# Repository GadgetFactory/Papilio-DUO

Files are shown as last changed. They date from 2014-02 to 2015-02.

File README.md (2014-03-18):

Papilio-DUO
==============
This is the next generation Papilio FPGA board with a Spartan6 Powered Papilio FPGA on the top and an atmega32u4 Arduino derived design on the bottom.

Features
--------
* Arduino Mega Footprint
* Spartan 6 FPGA
* SRAM 512K-2MB
* FT2232H USB
* atmega32u4 AVR

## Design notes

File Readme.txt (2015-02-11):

BPC3012 Papilio DUO Manufacturing Package - Current Version 1.7

Special assembly instructions:
	-Use RED for the PCB color and white for the silkscreen color.

Test Plan Home Page:
	- http://www.gadgetfactory.net/opmanuals/index.php?n=Main.PapilioDUO

CHANGELOG
2/11/2015 V1.7
	-Added a 2MB and 512KB marking to the top silkscreen.

1/7/2015 V1.6
	-Made the through holes for mounting on the micro-usb via's instead of holes so they can be soldered.
	-Removed Kickstarter edition
	-Fixed angles on some of the traces
	-PCB color is RED now.

9/30/2014 V1.5 - Kickstarter Edition
	-Added TQFP footprint for the ATmega32U4
	-Changed values for LED resistors so they won't be so bright. R7, R29, R30
	-Changed size of the EEPROM used by the FT2232H chip from 1K to 2K. This allows us to look like official Xilinx Cable. U3
	-Fixed up some silkscreen markings to make it more obvious how to place the parts.
	-Added the Kickstarter Special Edition Marking
	-Changed PCB color to Black

7/30/2014 V1.4
	-Added getting started URL
	-Fixed full silkscreen	

6/4/2014 V1.4
	-Fixed the mounting holes
	-Removed original Arduino mounting holes

4/16/2014 V1.3
	-VBUS connected
	-RX/TX LED's changed to port B
	-Silkscreen changes
	-HDMI removed

3/5/2014 V1.2
	-Shrunk the board to 100cm in order to better fit Chinese standards and save money in manufacturing.

3/5/2014 V1.1
	-Fixed problems for manufacturability (thanks to Mitch at Hackvana)
		-Fixed clearance problem on FPGA pins 144 and 36
		-Moved trace between FT2232H pins 10 and 11 to inside of part so it does not look like a solder bridge up on inspection.
		-Fixed Silkscreen size for the 22-53 numbering
		-Updated the CC-BY-SA text to indicate license number CC-BY-SA 4.0

3/3/2014 V1.0
	Initial Release

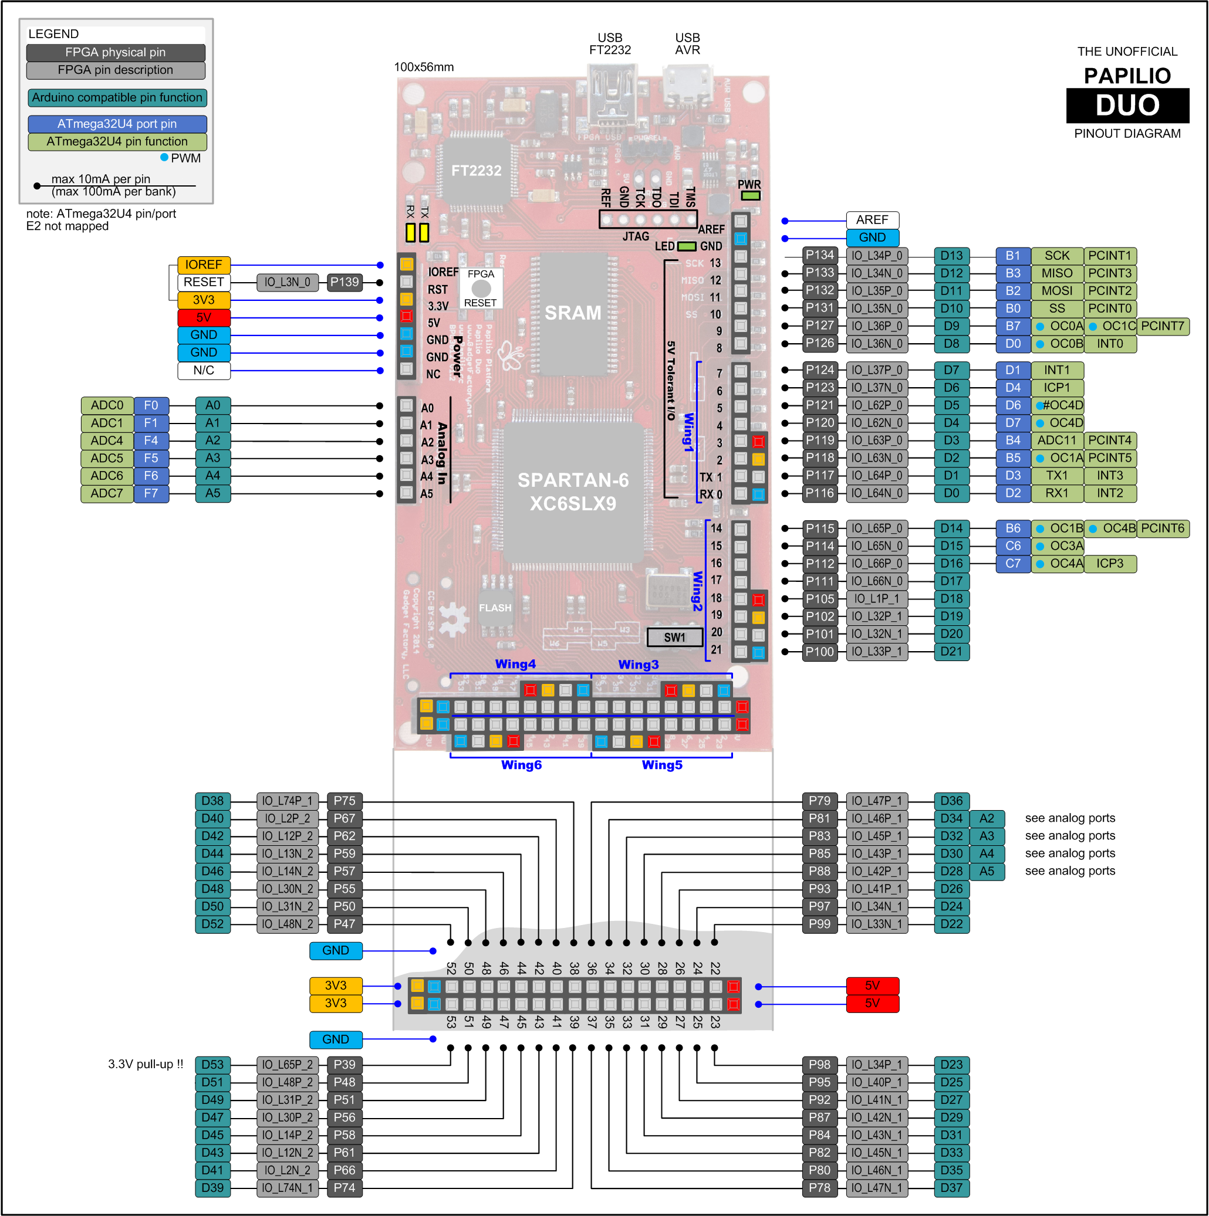
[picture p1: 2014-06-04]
Papilio DUO pinout.png

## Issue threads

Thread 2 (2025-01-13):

Papilio-One ?

nsauzede, 2025-01-13:
Hello!
I still have a working Papilio One 500k board, that I managed to undust and program fine,
but can't seem to find the corresponding schematics and design files, like found for the Duo in this repo.
Some pages of the original Gadgetfactory website (including Papilio One hardware doc etc..) seem to be unaccessible nowadays..
Would it be possible to upload a Papilio One github repo her, just like for the Duo and/or fix the Papilio One Gadgetfactory hardware doc webpages ?
Thanks by advance!

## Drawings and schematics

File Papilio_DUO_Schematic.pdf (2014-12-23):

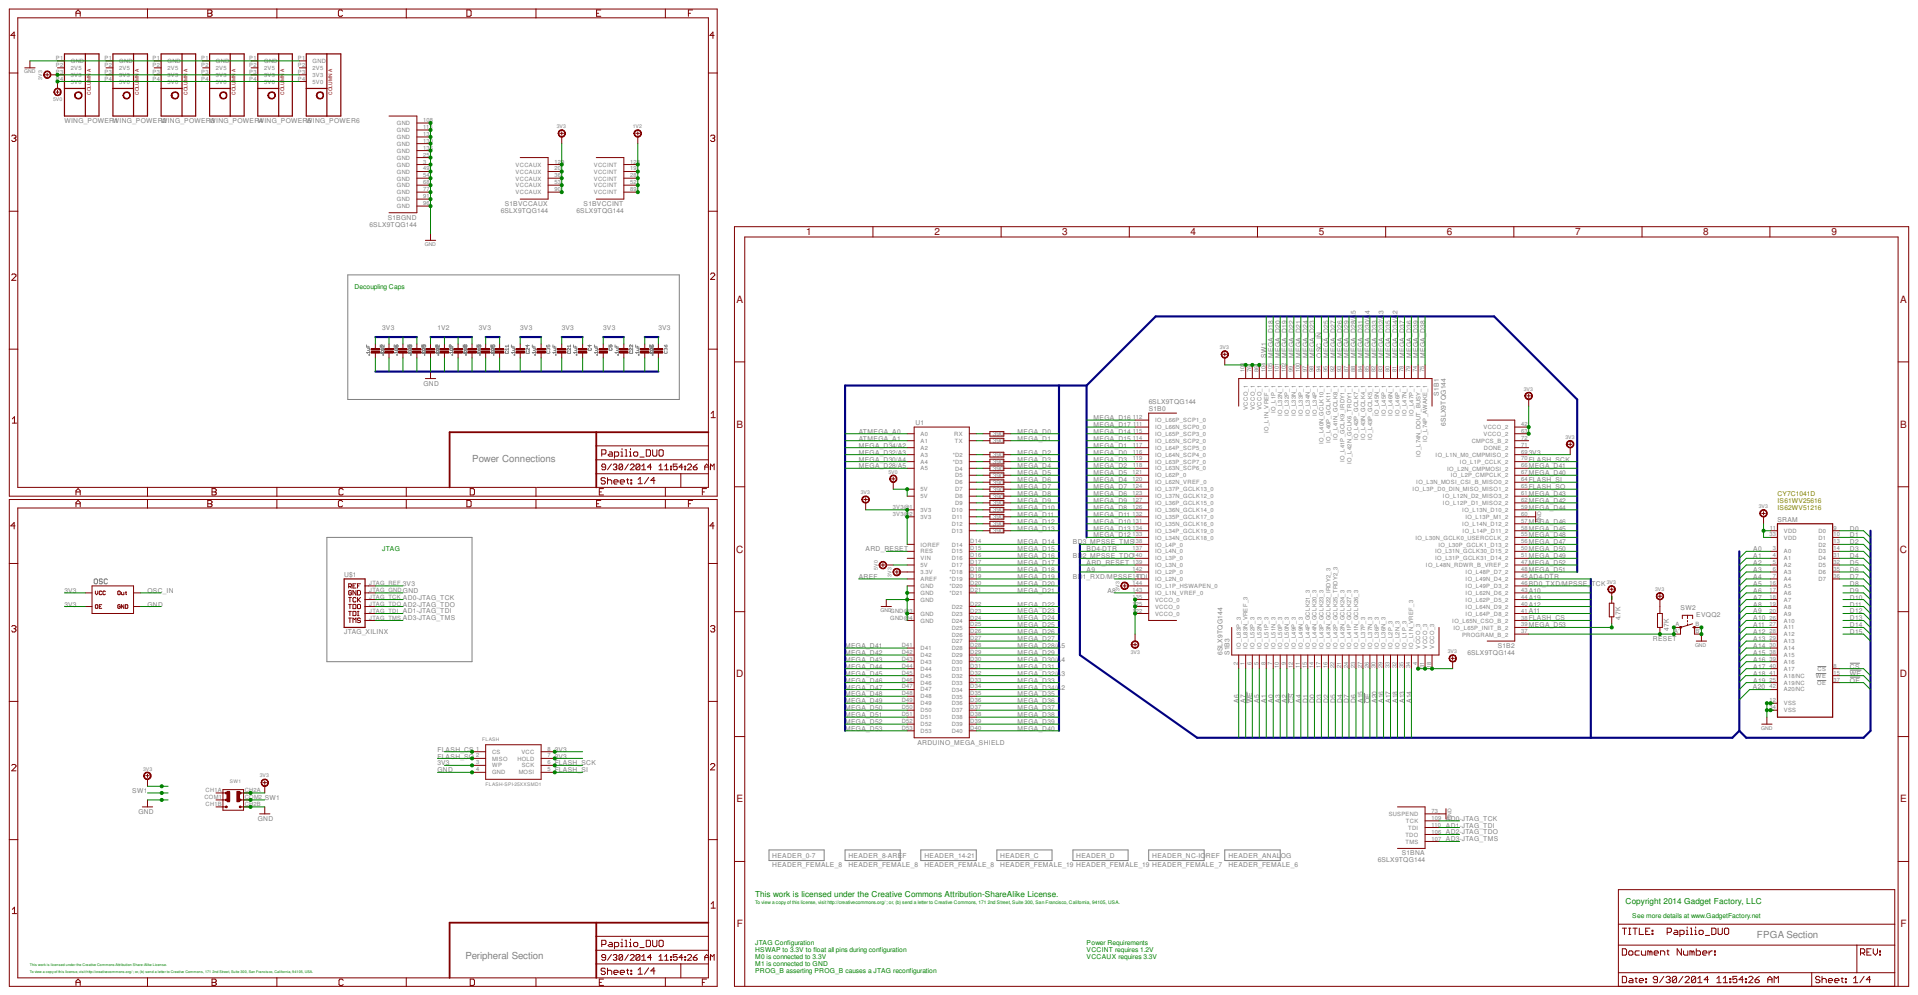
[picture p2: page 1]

MEGA_D53 | MEGA_D40

This work is licensed under the Creative Commons Attribution-ShareAlike License.
To view a copy of this license, visit http://creativecommons.org/ ; or, (b) send a letter to Creative Commons, 171 2nd Street, Suite 300, San Francisco, California, 94105, USA.

Copyright 2014 Gadget Factory, LLC

See more details at www.GadgetFactory.net

JTAG Configuration
HSWAP to 3.3V to float all pins during configuration
M0 is connected to 3.3V
M1 is connected to GND
PROG_B asserting PROG_B causes a JTAG reconfiguration

This work is licensed under the Creative Commons Attribution Share-Alike License.

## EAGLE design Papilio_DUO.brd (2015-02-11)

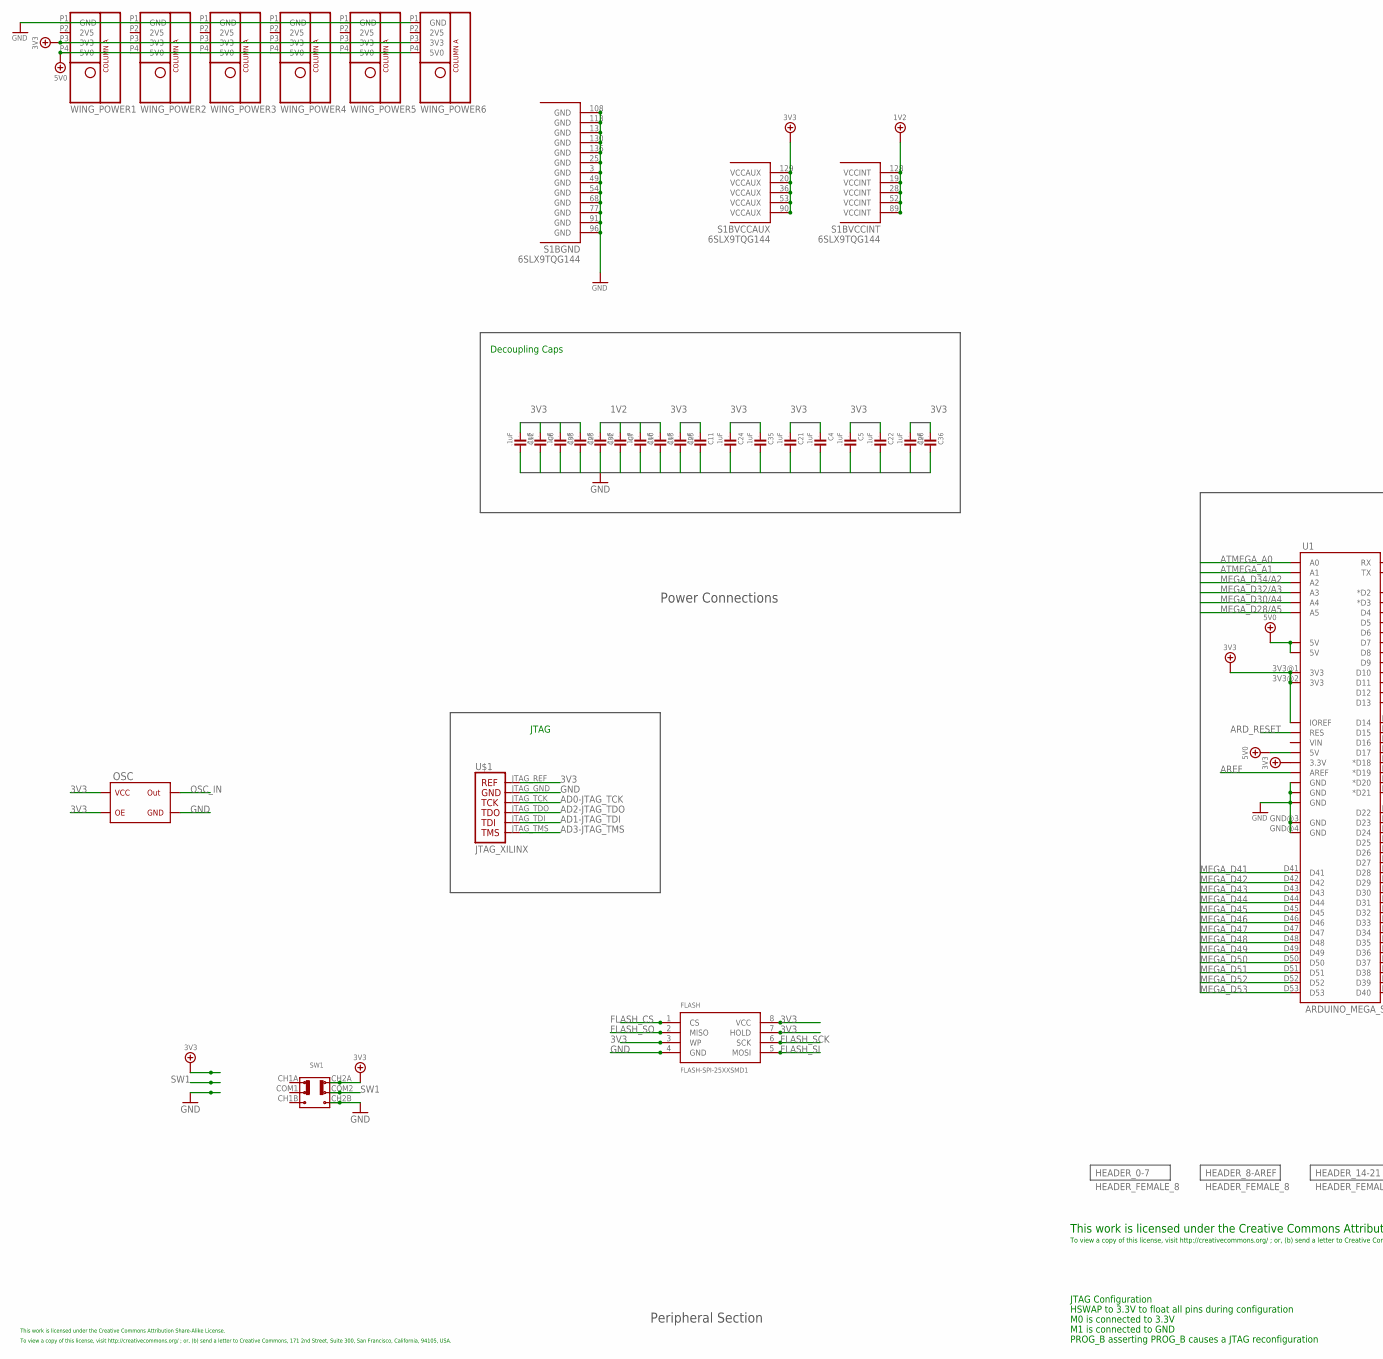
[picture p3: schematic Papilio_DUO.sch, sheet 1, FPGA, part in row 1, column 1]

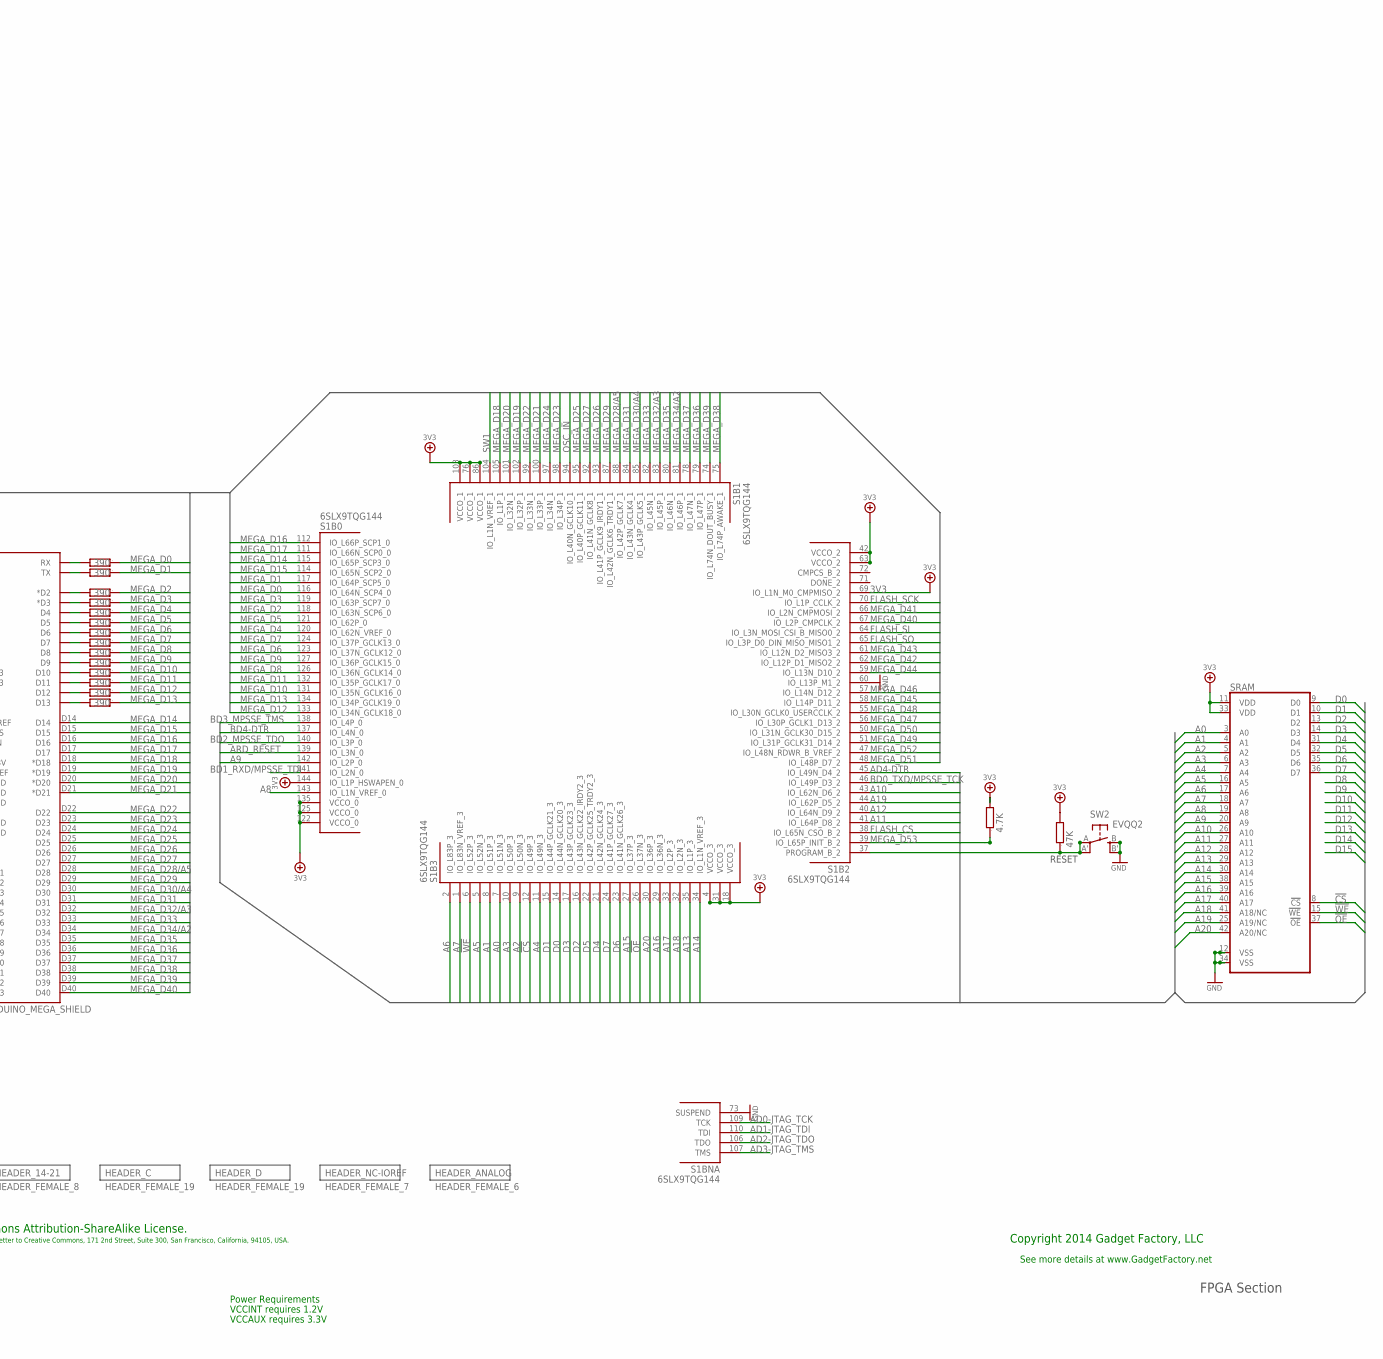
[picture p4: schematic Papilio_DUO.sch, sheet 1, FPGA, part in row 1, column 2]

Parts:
C4, C5, C6, C7, C10, C11, C12, C13, C21, C22, C23, C24, C25, C26, C32, C33, C35, C36: .1uF; 0603; PARTNO GRM188F51E104ZA01D
FLASH: FLASH-SPI-25XXSMD1; SO08-EIAJ; PARTNO MX25L6445EM2I-10G
OSC: OSC1; PARTNO ASV-32.000MHZ-E-T
R8, R9, R10, R11, R12, R13, R14, R15, R16, R17, R18, R19, R20, R21: 390; 0603; PARTNO RMCF0603JT390R
R31: 47K; 0805; PARTNO RMCF0805JT47K0
R32: 4.7K; 0603; PARTNO RMCF0603JT4K70
S1: 6SLX9TQG144; TQ144; PARTNO XC6SLX9-2TQG144C
SRAM: ISSI_SRAM_8BIT; TSOP44-II; PARTNO IS61WV20488BLL-10TLI
SW1: SWITCH-2CH-6P-3010010P1; 6P-2CH-2.54-9.1X3.5X3.2+2H; PARTNO EG1271
SW2: EVQQ2; EVQ-Q2; PARTNO PTS525SM10SMTR LFS
U1: ARDUINO_MEGA_SHIELD
U$1: JTAG_XILINX; JTAG
WING_POWER1, WING_POWER2, WING_POWER3, WING_POWER4, WING_POWER5, WING_POWER6: HEADER_FEMALE_4; POWER_NO_TEXT; PARTNO PPTC041LFBN-RC

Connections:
1V2: C7.1, C10.1, C13.1, C32.1, S1.19 (VCCINT), S1.28 (VCCINT), S1.52 (VCCINT), S1.89 (VCCINT), S1.128 (VCCINT); also elsewhere on the board
3V3: C4.1, C5.1, C6.1, C11.1, C12.1, C21.1, C22.1, C23.1, C24.1, C25.1, C26.1, C33.1, C35.1, C36.1, FLASH.3 (WP), FLASH.7 (HOLD), FLASH.8 (VCC), OSC.1@1 (OE), OSC.4@4 (VCC), R31.2, R32.2, S1.4 (VCCO_3), S1.18 (VCCO_3), S1.20 (VCCAUX), S1.31 (VCCO_3), S1.36 (VCCAUX), S1.42 (VCCO_2), S1.53 (VCCAUX), S1.63 (VCCO_2), S1.69 (IO_L1N_M0_CMPMISO_2), S1.76 (VCCO_1), S1.86 (VCCO_1), S1.90 (VCCAUX), S1.103 (VCCO_1), S1.122 (VCCO_0), S1.125 (VCCO_0), S1.129 (VCCAUX), S1.135 (VCCO_0), S1.144 (IO_L1P_HSWAPEN_0), SRAM.11 (VDD), SRAM.33 (VDD), SW1.CH2A, U1.3.3V, U1.3V3@1 (3V3), U1.3V3@2 (3V3), U1.IOREF, U$1.JTAG_REF, WING_POWER1.P3 (3V3), WING_POWER2.P3 (3V3), WING_POWER3.P3 (3V3), WING_POWER4.P3 (3V3), WING_POWER5.P3 (3V3), WING_POWER6.P3 (3V3); also elsewhere on the board
5V0: U1.5V@0 (5V), U1.5V@1 (5V), U1.5V@2 (5V), WING_POWER1.P4 (5V0), WING_POWER2.P4 (5V0), WING_POWER3.P4 (5V0), WING_POWER4.P4 (5V0), WING_POWER5.P4 (5V0), WING_POWER6.P4 (5V0); also elsewhere on the board
!CS: S1.12 (IO_L49P_3), SRAM.8 (!CS)
!OE: S1.26 (IO_L37N_3), SRAM.37 (!OE)
!WE: S1.6 (IO_L52P_3), SRAM.15 (!WE)
A0: S1.7 (IO_L51N_3), SRAM.3 (A0)
A1: S1.8 (IO_L51P_3), SRAM.4 (A1)
A2: S1.9 (IO_L50N_3), SRAM.5 (A2)
A3: S1.10 (IO_L50P_3), SRAM.6 (A3)
A4: S1.11 (IO_L49N_3), SRAM.7 (A4)
A5: S1.5 (IO_L52N_3), SRAM.16 (A5)
A6: S1.2 (IO_L83P_3), SRAM.17 (A6)
A7: S1.1 (IO_L83N_VREF_3), SRAM.18 (A7)
A8: S1.143 (IO_L1N_VREF_0), SRAM.19 (A8)
A9: S1.142 (IO_L2P_0), SRAM.20 (A9)
A10: S1.43 (IO_L62N_D6_2), SRAM.26 (A10)
A11: S1.41 (IO_L64P_D8_2), SRAM.27 (A11)
A12: S1.40 (IO_L64N_D9_2), SRAM.28 (A12)
A13: S1.35 (IO_L1P_3), SRAM.29 (A13)
A14: S1.34 (IO_L1N_VREF_3), SRAM.30 (A14)
A15: S1.27 (IO_L37P_3), SRAM.38 (A15)
A16: S1.29 (IO_L36N_3), SRAM.39 (A16)
A17: S1.33 (IO_L2P_3), SRAM.40 (A17)
A18: S1.32 (IO_L2N_3), SRAM.41 (A18/NC)
A19: S1.44 (IO_L62P_D5_2), SRAM.25 (A19/NC)
A20: S1.30 (IO_L36P_3), SRAM.42 (A20/NC)
AD0-JTAG_TCK: S1.109 (TCK), U$1.JTAG_TCK; also elsewhere on the board
AD1-JTAG_TDI: S1.110 (TDI), U$1.JTAG_TDI; also elsewhere on the board
AD2-JTAG_TDO: S1.106 (TDO), U$1.JTAG_TDO; also elsewhere on the board
AD3-JTAG_TMS: S1.107 (TMS), U$1.JTAG_TMS; also elsewhere on the board
AD4-DTR: S1.45 (IO_L49N_D4_2); also elsewhere on the board
ARD_RESET: S1.139 (IO_L3N_0), U1.RES; also elsewhere on the board
AREF: U1.AREF; also elsewhere on the board
ATMEGA_A0: U1.A0; also elsewhere on the board
ATMEGA_A1: U1.A1; also elsewhere on the board
ATMEGA_D0/RX: R21.2, U1.RX; also elsewhere on the board
ATMEGA_D1/TX: R20.2, U1.TX; also elsewhere on the board
ATMEGA_D2: R19.2, U1.D2 (*D2); also elsewhere on the board
ATMEGA_D3: R18.2, U1.D3 (*D3); also elsewhere on the board
ATMEGA_D4: R17.2, U1.D4; also elsewhere on the board
ATMEGA_D5*: R16.2, U1.D5; also elsewhere on the board
ATMEGA_D6*: R15.2, U1.D6; also elsewhere on the board
ATMEGA_D7: R14.2, U1.D7; also elsewhere on the board
ATMEGA_IO8: R13.2, U1.D8; also elsewhere on the board
ATMEGA_IO9*: R12.2, U1.D9; also elsewhere on the board
ATMEGA_IO10*: R11.2, U1.D10; also elsewhere on the board
ATMEGA_IO11*: R10.2, U1.D11; also elsewhere on the board
ATMEGA_IO12: R9.2, U1.D12; also elsewhere on the board
ATMEGA_IO13*: R8.2, U1.D13; also elsewhere on the board
BD0_TXD/MPSSE_TCK: S1.46 (IO_L49P_D3_2); also elsewhere on the board
BD1_RXD/MPSSE_TDI: S1.141 (IO_L2N_0); also elsewhere on the board
BD2_MPSSE_TDO: S1.140 (IO_L3P_0); also elsewhere on the board
BD3_MPSSE_TMS: S1.138 (IO_L4P_0); also elsewhere on the board
BD4-DTR: S1.137 (IO_L4N_0); also elsewhere on the board
D0: S1.14 (IO_L44N_GCLK20_3), SRAM.9 (D0)
D1: S1.15 (IO_L44P_GCLK21_3), SRAM.10 (D1)
D2: S1.16 (IO_L43N_GCLK22_IRDY2_3), SRAM.13 (D2)
D3: S1.17 (IO_L43P_GCLK23_3), SRAM.14 (D3)
D4: S1.21 (IO_L42N_GCLK24_3), SRAM.31 (D4)
D5: S1.22 (IO_L42P_GCLK25_TRDY2_3), SRAM.32 (D5)
D6: S1.23 (IO_L41N_GCLK26_3), SRAM.35 (D6)
D7: S1.24 (IO_L41P_GCLK27_3), SRAM.36 (D7)
FLASH_CS: FLASH.1 (CS), S1.38 (IO_L65N_CSO_B_2)
FLASH_SCK: FLASH.6 (SCK), S1.70 (IO_L1P_CCLK_2)
FLASH_SI: FLASH.5 (MOSI), S1.64 (IO_L3N_MOSI_CSI_B_MISO0_2)
FLASH_SO: FLASH.2 (MISO), S1.65 (IO_L3P_D0_DIN_MISO_MISO1_2)
GND: C4.2, C5.2, C6.2, C7.2, C10.2, C11.2, C12.2, C13.2, C21.2, C22.2, C23.2, C24.2, C25.2, C26.2, C32.2, C33.2, C35.2, C36.2, FLASH.4 (GND), OSC.2@2 (GND), S1.3 (GND), S1.13 (GND), S1.25 (GND), S1.49 (GND), S1.54 (GND), S1.60 (IO_L13P_M1_2), S1.68 (GND), S1.73 (SUSPEND), S1.77 (GND), S1.91 (GND), S1.96 (GND), S1.108 (GND), S1.113 (GND), S1.130 (GND), S1.136 (GND), SRAM.12 (VSS), SRAM.34 (VSS), SW1.CH2B, SW2.B (S), SW2.B' (S1), U1.GND@0 (GND), U1.GND@1 (GND), U1.GND@2 (GND), U1.GND@3 (GND), U1.GND@4 (GND), U$1.JTAG_GND, WING_POWER1.P1 (GND), WING_POWER2.P1 (GND), WING_POWER3.P1 (GND), WING_POWER4.P1 (GND), WING_POWER5.P1 (GND), WING_POWER6.P1 (GND); also elsewhere on the board
MEGA_D0: R21.1, S1.116 (IO_L64N_SCP4_0)
MEGA_D1: R20.1, S1.117 (IO_L64P_SCP5_0)
MEGA_D2: R19.1, S1.118 (IO_L63N_SCP6_0)
MEGA_D3: R18.1, S1.119 (IO_L63P_SCP7_0)
MEGA_D4: R17.1, S1.120 (IO_L62N_VREF_0)
MEGA_D5: R16.1, S1.121 (IO_L62P_0)
MEGA_D6: R15.1, S1.123 (IO_L37N_GCLK12_0)
MEGA_D7: R14.1, S1.124 (IO_L37P_GCLK13_0)
MEGA_D8: R13.1, S1.126 (IO_L36N_GCLK14_0)
MEGA_D9: R12.1, S1.127 (IO_L36P_GCLK15_0)
MEGA_D10: R11.1, S1.131 (IO_L35N_GCLK16_0)
MEGA_D11: R10.1, S1.132 (IO_L35P_GCLK17_0)
MEGA_D12: R9.1, S1.133 (IO_L34N_GCLK18_0)
MEGA_D13: R8.1, S1.134 (IO_L34P_GCLK19_0)
MEGA_D14: S1.115 (IO_L65P_SCP3_0), U1.D14; also elsewhere on the board
MEGA_D15: S1.114 (IO_L65N_SCP2_0), U1.D15; also elsewhere on the board
MEGA_D16: S1.112 (IO_L66P_SCP1_0), U1.D16; also elsewhere on the board
MEGA_D17: S1.111 (IO_L66N_SCP0_0), U1.D17
MEGA_D18: S1.105 (IO_L1P_1), U1.D18 (*D18)
MEGA_D19: S1.102 (IO_L32P_1), U1.D19 (*D19)
MEGA_D20: S1.101 (IO_L32N_1), U1.D20 (*D20)
MEGA_D21: S1.100 (IO_L33P_1), U1.D21 (*D21)
MEGA_D22: S1.99 (IO_L33N_1), U1.D22
MEGA_D23: S1.98 (IO_L34P_1), U1.D23
MEGA_D24: S1.97 (IO_L34N_1), U1.D24
MEGA_D25: S1.95 (IO_L40P_GCLK11_1), U1.D25
MEGA_D26: S1.93 (IO_L41P_GCLK9_IRDY1_1), U1.D26
MEGA_D27: S1.92 (IO_L41N_GCLK8_1), U1.D27
MEGA_D28/A5: S1.88 (IO_L42P_GCLK7_1), U1.A5, U1.D28; also elsewhere on the board
MEGA_D29: S1.87 (IO_L42N_GCLK6_TRDY1_1), U1.D29
MEGA_D30/A4: S1.85 (IO_L43P_GCLK5_1), U1.A4, U1.D30; also elsewhere on the board
MEGA_D31: S1.84 (IO_L43N_GCLK4_1), U1.D31
MEGA_D32/A3: S1.83 (IO_L45P_1), U1.A3, U1.D32; also elsewhere on the board
MEGA_D33: S1.82 (IO_L45N_1), U1.D33
MEGA_D34/A2: S1.81 (IO_L46P_1), U1.A2, U1.D34; also elsewhere on the board
MEGA_D35: S1.80 (IO_L46N_1), U1.D35
MEGA_D36: S1.79 (IO_L47P_1), U1.D36
MEGA_D37: S1.78 (IO_L47N_1), U1.D37
MEGA_D38: S1.75 (IO_L74P_AWAKE_1), U1.D38
MEGA_D39: S1.74 (IO_L74N_DOUT_BUSY_1), U1.D39
MEGA_D40: S1.67 (IO_L2P_CMPCLK_2), U1.D40
MEGA_D41: S1.66 (IO_L2N_CMPMOSI_2), U1.D41
MEGA_D42: S1.62 (IO_L12P_D1_MISO2_2), U1.D42
MEGA_D43: S1.61 (IO_L12N_D2_MISO3_2), U1.D43
MEGA_D44: S1.59 (IO_L13N_D10_2), U1.D44
MEGA_D45: S1.58 (IO_L14P_D11_2), U1.D45
MEGA_D46: S1.57 (IO_L14N_D12_2), U1.D46
MEGA_D47: S1.56 (IO_L30P_GCLK1_D13_2), U1.D47
MEGA_D48: S1.55 (IO_L30N_GCLK0_USERCCLK_2), U1.D48
MEGA_D49: S1.51 (IO_L31P_GCLK31_D14_2), U1.D49
MEGA_D50: S1.50 (IO_L31N_GCLK30_D15_2), U1.D50
MEGA_D51: S1.48 (IO_L48P_D7_2), U1.D51
MEGA_D52: S1.47 (IO_L48N_RDWR_B_VREF_2), U1.D52
MEGA_D53: R32.1, S1.39 (IO_L65P_INIT_B_2), U1.D53
OSC_IN: OSC.3@3 (OUT), S1.94 (IO_L40N_GCLK10_1)
RESET: R31.1, S1.37 (PROGRAM_B_2), SW2.A, SW2.A' (P1)
SW1: S1.104 (IO_L1N_VREF_1), SW1.COM2

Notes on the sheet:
JTAG Configuration
HSWAP to 3.3V to float all pins during configuration
M0 is connected to 3.3V
M1 is connected to GND
PROG_B asserting PROG_B causes a JTAG reconfiguration
Power Requirements
VCCINT requires 1.2V
VCCAUX requires 3.3V
Decoupling Caps
JTAG
Copyright 2014 Gadget Factory, LLC
This work is licensed under the Creative Commons Attribution-ShareAlike License.
To view a copy of this license, visit http://creativecommons.org/ ; or, (b) send a letter to Creative Commons, 171 2nd Street, Suite 300, San Francisco, California, 94105, USA.
See more details at www.GadgetFactory.net
This work is licensed under the Creative Commons Attribution Share-Alike License.
Power Connections
Peripheral Section
FPGA Section
RESET

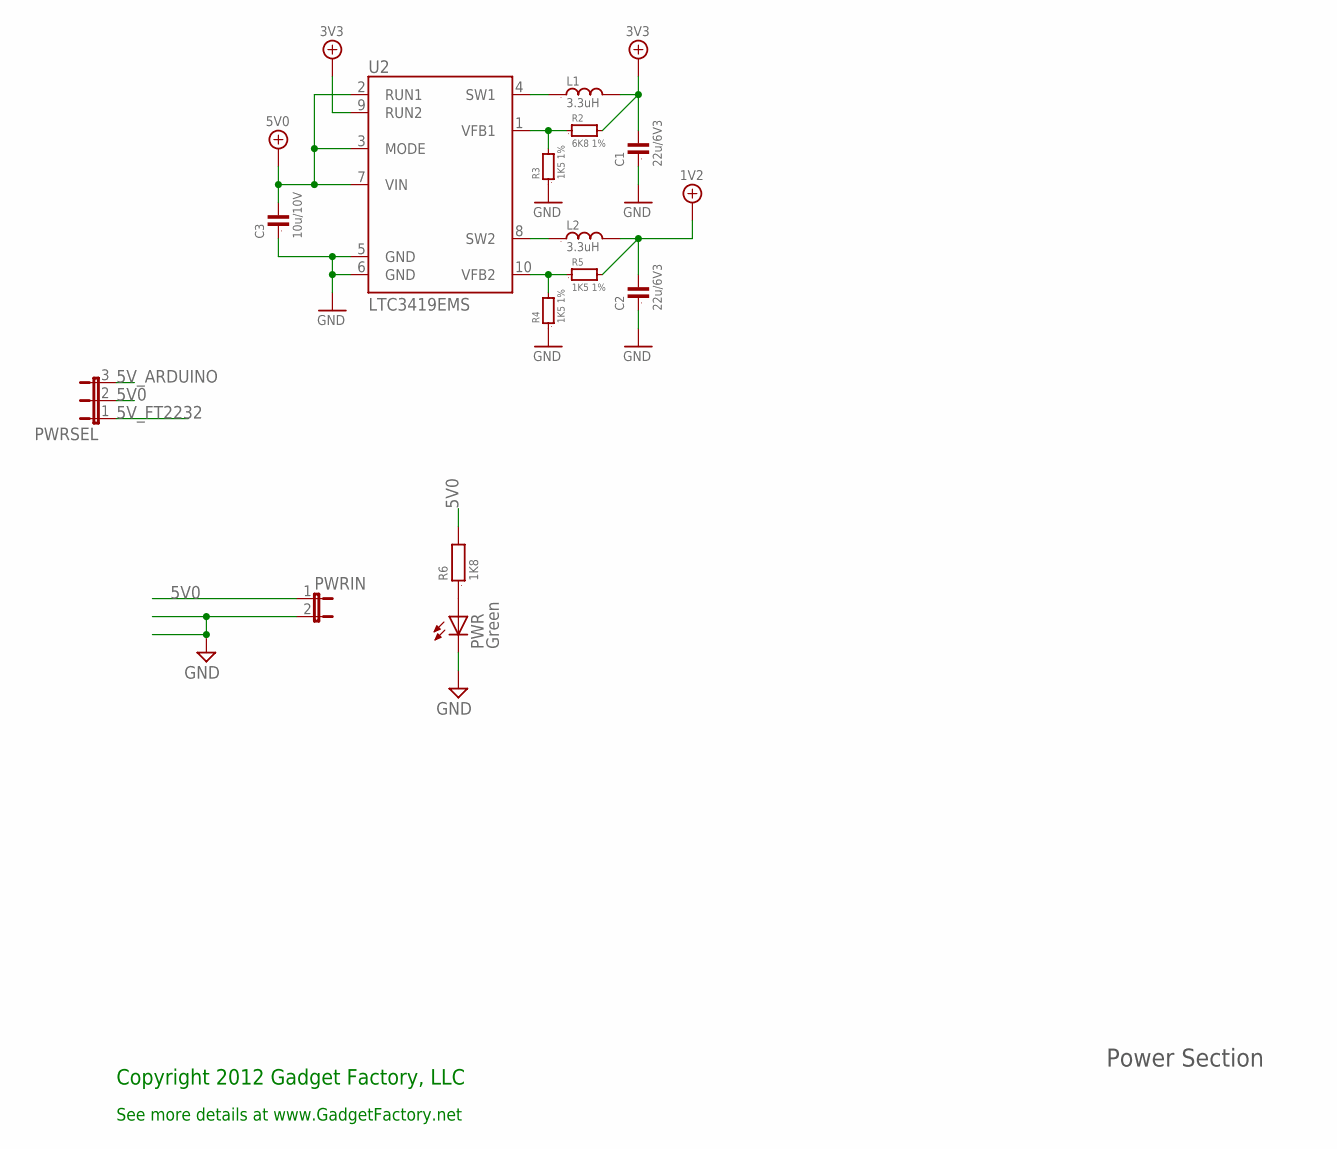
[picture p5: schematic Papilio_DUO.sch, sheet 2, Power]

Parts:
C1, C2: 22u/6V3; 0805; PARTNO GRM21BR60J226ME39L
C3: 10u/10V; 0805; PARTNO C0805C106K9PACTU
L1, L2: 3.3uH; VLS3015; PARTNO VLS3015T-3R3M1R2
PWR: Green; CHIP-LED0805; PARTNO LTST-C171EKT
PWRIN: JP1E; JP1; PARTNO 68000-102HLF
PWRSEL: JP2E; JP2; PARTNO 68000-103HLF
R2: 6K8 1%; 0603; PARTNO CRCW06036K80FKEA
R3, R4, R5: 1K5 1%; 0603; PARTNO CRCW06031K50FKEA
R6: 1K8; 0603; PARTNO RMCF0603JT1K80
U2: LTC3419EMS; MSOP10; PARTNO LTC3419EMS#PBF

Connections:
1V2: C2.2, L2.2, R5.2; also elsewhere on the board
3V3: C1.2, L1.2, R2.2, U2.9 (RUN2); also elsewhere on the board
5V0: C3.2, PWRIN.1, PWRSEL.2, R6.2, U2.2 (RUN1), U2.3 (MODE), U2.7 (VIN); also elsewhere on the board
5V_ARDUINO: PWRSEL.3; also elsewhere on the board
5V_FT2232: PWRSEL.1; also elsewhere on the board
FB_1V2: R4.2, R5.1, U2.10 (VFB2)
FB_3V3: R2.1, R3.2, U2.1 (VFB1)
GND: C1.1, C2.1, C3.1, PWR.C, PWRIN.2, R3.1, R4.1, U2.5 (GND), U2.6 (GND); also elsewhere on the board
unnamed: PWR.A, R6.1
SW_1V2: L2.1, U2.8 (SW2)
SW_3V3: L1.1, U2.4 (SW1)

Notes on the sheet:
Power Section
Copyright 2012 Gadget Factory, LLC
See more details at www.GadgetFactory.net

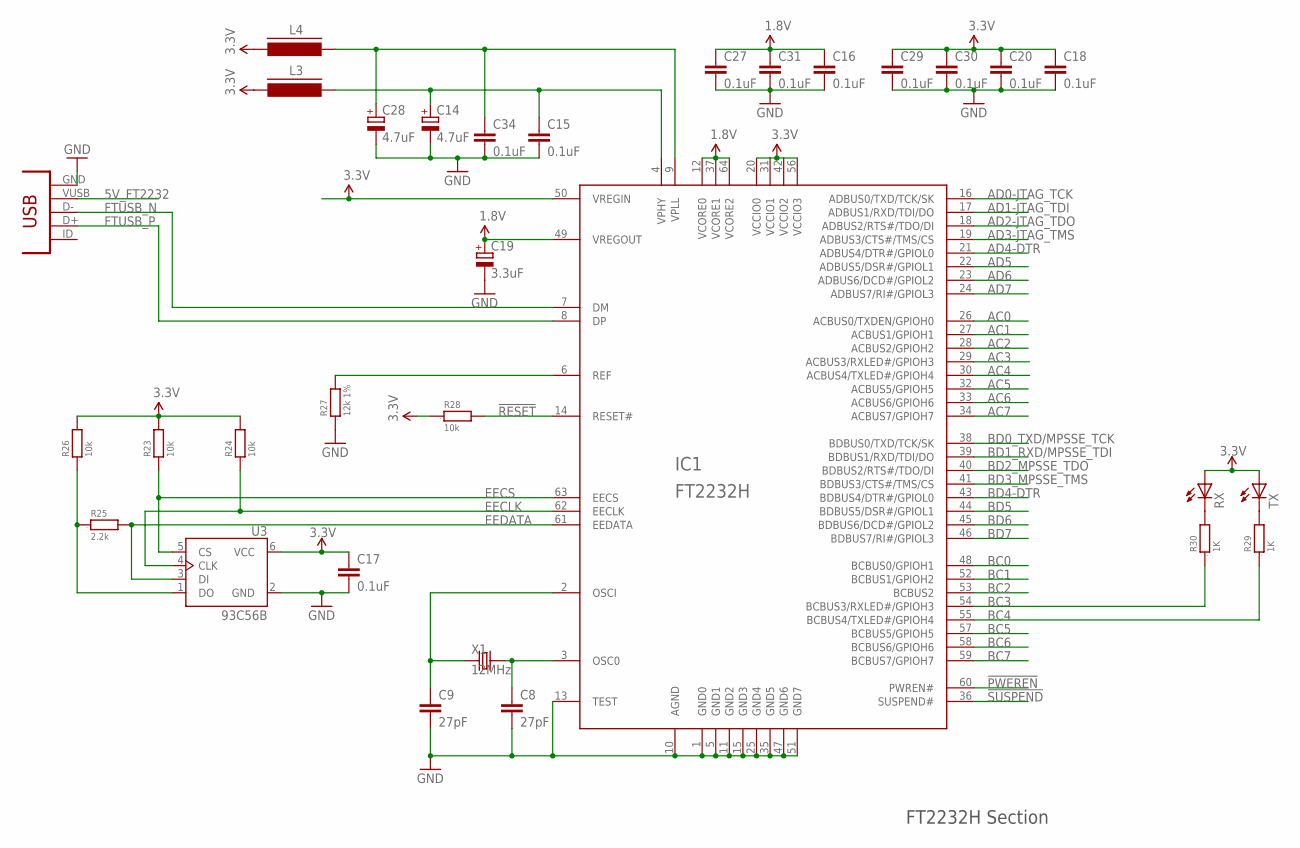
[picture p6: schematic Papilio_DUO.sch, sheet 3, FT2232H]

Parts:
C8, C9: 27pF; C603; PARTNO CL10C270JB8NNNC
C14, C28: 4.7uF; SMC_A; PARTNO T491A475M010AT
C15, C16, C17, C18, C20, C27, C29, C30, C31, C34: 0.1uF; C603; PARTNO GRM188F51E104ZA01D
C19: 3.3uF; SMC_A; PARTNO T491A335K016AT7280
FPGAUSB: CONN_USB; CONN_USB_MINI-B; PARTNO USB-M26FTR
IC1: FT2232H; LQFP64; PARTNO FT2232HL-REEL
L3, L4: FERRITE_BEAD603; FB603; PARTNO MMZ1608R600A
R23, R24, R26, R28: 10k; 0603; PARTNO RMCF0603JT10K0
R25: 2.2k; 0603; PARTNO RMCF0603JT2K20
R27: 12k 1%; 0603; PARTNO RMCF0603FT12K0
R29, R30: 1K; 0603; PARTNO RMCF0603JT470R
RX: LEDCHIP-LED0805; CHIP-LED0805; PARTNO LTST-C170KGKT
TX: LEDCHIP-LED0805; CHIP-LED0805; PARTNO LTST-C170KGKT
U3: 93C56B; SOT23-6; PARTNO 93C46BT-I/OT
X1: 12MHz; 4X6; PARTNO ABM7-12.000MHZ-D2Y-T

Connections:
1.8V: C16.1, C19.+, C27.1, C31.1, IC1.12 (VCORE0), IC1.37 (VCORE1), IC1.49 (VREGOUT), IC1.64 (VCORE2)
3V3: C17.1, C18.1, C20.1, C29.1, C30.1, IC1.20 (VCCIO0), IC1.31 (VCCIO1), IC1.42 (VCCIO2), IC1.50 (VREGIN), IC1.56 (VCCIO3), L3.2, L4.2, R23.2, R24.2, R26.2, R28.1, RX.A, TX.A, U3.6 (VCC); also elsewhere on the board
5V_FT2232: FPGAUSB.VUSB; also elsewhere on the board
!PWEREN: IC1.60 (PWREN#)
!RESET: IC1.14 (RESET#), R28.2
!SUSPEND: IC1.36 (SUSPEND#)
AC0: IC1.26 (ACBUS0/TXDEN/GPIOH0)
AC1: IC1.27 (ACBUS1/GPIOH1)
AC2: IC1.28 (ACBUS2/GPIOH2)
AC3: IC1.29 (ACBUS3/RXLED#/GPIOH3)
AC4: IC1.30 (ACBUS4/TXLED#/GPIOH4)
AC5: IC1.32 (ACBUS5/GPIOH5)
AC6: IC1.33 (ACBUS6/GPIOH6)
AC7: IC1.34 (ACBUS7/GPIOH7)
AD0-JTAG_TCK: IC1.16 (ADBUS0/TXD/TCK/SK); also elsewhere on the board
AD1-JTAG_TDI: IC1.17 (ADBUS1/RXD/TDI/DO); also elsewhere on the board
AD2-JTAG_TDO: IC1.18 (ADBUS2/RTS#/TDO/DI); also elsewhere on the board
AD3-JTAG_TMS: IC1.19 (ADBUS3/CTS#/TMS/CS); also elsewhere on the board
AD4-DTR: IC1.21 (ADBUS4/DTR#/GPIOL0); also elsewhere on the board
AD5: IC1.22 (ADBUS5/DSR#/GPIOL1)
AD6: IC1.23 (ADBUS6/DCD#/GPIOL2)
AD7: IC1.24 (ADBUS7/RI#/GPIOL3)
BC0: IC1.48 (BCBUS0/GPIOH1)
BC1: IC1.52 (BCBUS1/GPIOH2)
BC2: IC1.53 (BCBUS2)
BC3: IC1.54 (BCBUS3/RXLED#/GPIOH3), R30.1
BC4: IC1.55 (BCBUS4/TXLED#/GPIOH4), R29.1
BC5: IC1.57 (BCBUS5/GPIOH5)
BC6: IC1.58 (BCBUS6/GPIOH6)
BC7: IC1.59 (BCBUS7/GPIOH7)
BD0_TXD/MPSSE_TCK: IC1.38 (BDBUS0/TXD/TCK/SK); also elsewhere on the board
BD1_RXD/MPSSE_TDI: IC1.39 (BDBUS1/RXD/TDI/DO); also elsewhere on the board
BD2_MPSSE_TDO: IC1.40 (BDBUS2/RTS#/TDO/DI); also elsewhere on the board
BD3_MPSSE_TMS: IC1.41 (BDBUS3/CTS#/TMS/CS); also elsewhere on the board
BD4-DTR: IC1.43 (BDBUS4/DTR#/GPIOL0); also elsewhere on the board
BD5: IC1.44 (BDBUS5/DSR#/GPIOL1)
BD6: IC1.45 (BDBUS6/DCD#/GPIOL2)
BD7: IC1.46 (BDBUS7/RI#/GPIOL3)
EECLK: IC1.62 (EECLK), R24.1, U3.4 (CLK)
EECS: IC1.63 (EECS), R23.1, U3.5 (CS)
EEDATA: IC1.61 (EEDATA), R25.2, U3.3 (DI)
FTUSB_N: FPGAUSB.D-, IC1.7 (DM)
FTUSB_P: FPGAUSB.D+, IC1.8 (DP)
GND: C8.2, C9.2, C14.-, C15.2, C16.2, C17.2, C18.2, C19.-, C20.2, C27.2, C28.-, C29.2, C30.2, C31.2, C34.2, FPGAUSB.GND, IC1.1 (GND0), IC1.5 (GND1), IC1.10 (AGND), IC1.11 (GND2), IC1.13 (TEST), IC1.15 (GND3), IC1.25 (GND4), IC1.35 (GND5), IC1.47 (GND6), IC1.51 (GND7), R27.1, U3.2 (GND); also elsewhere on the board
unnamed: IC1.6 (REF), R27.2
unnamed: C9.1, IC1.2 (OSCI), X1.1 (X1)
unnamed: C8.1, IC1.3 (OSC0), X1.2 (X2)
unnamed: R30.2, RX.C
unnamed: R29.2, TX.C
unnamed: R25.1, R26.1, U3.1 (DO)
unnamed: C14.+, C15.1, IC1.4 (VPHY), L3.1
unnamed: C28.+, C34.1, IC1.9 (VPLL), L4.1

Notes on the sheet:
FT2232H Section

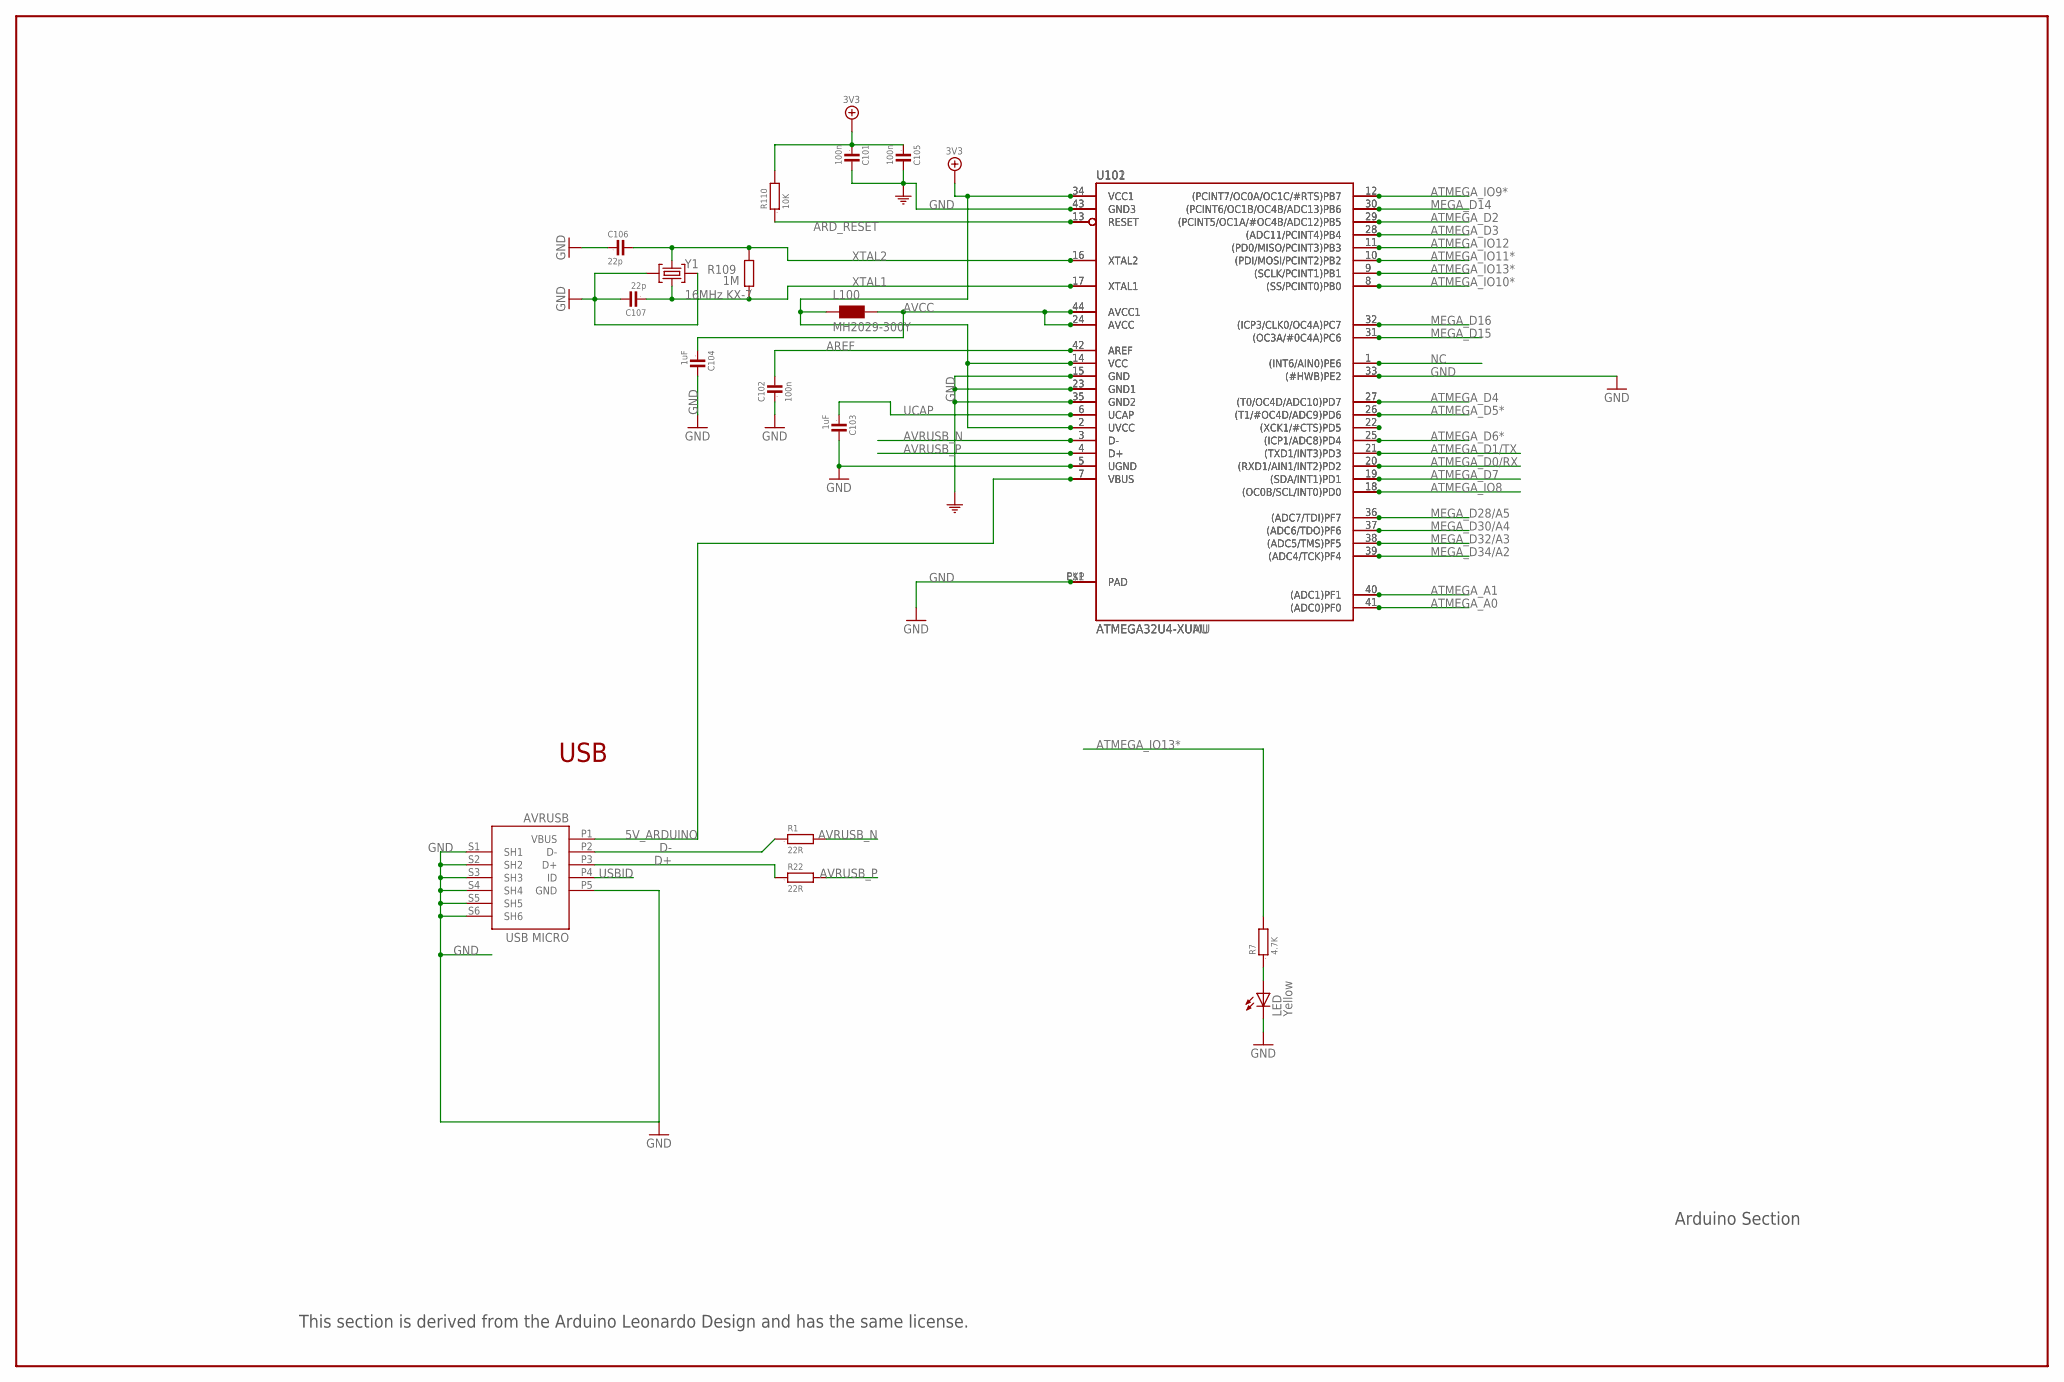
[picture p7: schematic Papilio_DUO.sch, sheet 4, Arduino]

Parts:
AVRUSB: USB MICRO; CON2_USB_MICRO_B_AT; PARTNO 10118193-0001LF
C101, C102, C105: 100n; 0603; PARTNO GRM188F51E104ZA01D
C103, C104: 1uF; 0603; PARTNO C1608X5R1A105K080AC
C106, C107: 22p; 0603; PARTNO C1608C0G1H220J080AA
L100: MH2029-300Y; 0805; PARTNO MH2029-300YCT-ND
LED: Yellow; CHIP-LED0805; PARTNO LTST-C170KGKT
R1, R22: 22R; 0805; PARTNO RMCF0805JT22R0
R7: 4.7K; 0603; PARTNO RMCF0603JT1K00
R109: 1M; 0603; PARTNO RMCF0603JT1M00
R110: 10K; 0603; PARTNO RMCF0603JT10K0
U101: ATMEGA32U4-XUMU; QFN44ML7X7; PARTNO ATMEGA32U4RC-MUR
U102: ATMEGA32U4-XUAU; TQFP44-PAD
Y1: 16MHz KX-7; CRYSTAL-3.2-2.5; PARTNO ABM8G-16.000MHZ-B4Y-T

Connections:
3V3: C101.1, C105.1, L100.1, R110.2, U101.2 (UVCC), U101.14 (VCC), U101.34 (VCC1), U102.2 (UVCC), U102.14 (VCC), U102.34 (VCC1); also elsewhere on the board
5V_ARDUINO: AVRUSB.P1 (VBUS), U101.7 (VBUS), U102.7 (VBUS); also elsewhere on the board
ARD_RESET: R110.1, U101.13 (RESET), U102.13 (RESET); also elsewhere on the board
AREF: C102.2, U101.42 (AREF), U102.42 (AREF); also elsewhere on the board
ATMEGA_A0: U101.41 ((ADC0)PF0), U102.41 ((ADC0)PF0); also elsewhere on the board
ATMEGA_A1: U101.40 ((ADC1)PF1), U102.40 ((ADC1)PF1); also elsewhere on the board
ATMEGA_D0/RX: U101.20 ((RXD1/AIN1/INT2)PD2), U102.20 ((RXD1/AIN1/INT2)PD2); also elsewhere on the board
ATMEGA_D1/TX: U101.21 ((TXD1/INT3)PD3), U102.21 ((TXD1/INT3)PD3); also elsewhere on the board
ATMEGA_D2: U101.29 ((PCINT5/OC1A/#OC4B/ADC12)PB5), U102.29 ((PCINT5/OC1A/#OC4B/ADC12)PB5); also elsewhere on the board
ATMEGA_D3: U101.28 ((ADC11/PCINT4)PB4), U102.28 ((ADC11/PCINT4)PB4); also elsewhere on the board
ATMEGA_D4: U101.27 ((T0/OC4D/ADC10)PD7), U102.27 ((T0/OC4D/ADC10)PD7); also elsewhere on the board
ATMEGA_D5*: U101.26 ((T1/#OC4D/ADC9)PD6), U102.26 ((T1/#OC4D/ADC9)PD6); also elsewhere on the board
ATMEGA_D6*: U101.25 ((ICP1/ADC8)PD4), U102.25 ((ICP1/ADC8)PD4); also elsewhere on the board
ATMEGA_D7: U101.19 ((SDA/INT1)PD1), U102.19 ((SDA/INT1)PD1); also elsewhere on the board
ATMEGA_IO8: U101.18 ((OC0B/SCL/INT0)PD0), U102.18 ((OC0B/SCL/INT0)PD0); also elsewhere on the board
ATMEGA_IO9*: U101.12 ((PCINT7/OC0A/OC1C/#RTS)PB7), U102.12 ((PCINT7/OC0A/OC1C/#RTS)PB7); also elsewhere on the board
ATMEGA_IO10*: U101.8 ((SS/PCINT0)PB0), U102.8 ((SS/PCINT0)PB0); also elsewhere on the board
ATMEGA_IO11*: U101.10 ((PDI/MOSI/PCINT2)PB2), U102.10 ((PDI/MOSI/PCINT2)PB2); also elsewhere on the board
ATMEGA_IO12: U101.11 ((PD0/MISO/PCINT3)PB3), U102.11 ((PD0/MISO/PCINT3)PB3); also elsewhere on the board
ATMEGA_IO13*: R7.2, U101.9 ((SCLK/PCINT1)PB1), U102.9 ((SCLK/PCINT1)PB1); also elsewhere on the board
AVCC: C104.1, L100.2, U101.24 (AVCC), U101.44 (AVCC1), U102.24 (AVCC), U102.44 (AVCC1)
AVRUSB_N: R1.2, U101.3 (D-), U102.3 (D-)
AVRUSB_P: R22.2, U101.4 (D+), U102.4 (D+)
D+: AVRUSB.P3 (D+), R22.1
D-: AVRUSB.P2 (D-), R1.1
GND: AVRUSB.P5 (GND), AVRUSB.S1 (SH1), AVRUSB.S2 (SH2), AVRUSB.S3 (SH3), AVRUSB.S4 (SH4), AVRUSB.S5 (SH5), AVRUSB.S6 (SH6), C101.2, C102.1, C103.2, C104.2, C105.2, C106.1, C107.2, LED.C, U101.5 (UGND), U101.15 (GND), U101.23 (GND1), U101.33 ((#HWB)PE2), U101.35 (GND2), U101.43 (GND3), U101.EXP (PAD), U102.5 (UGND), U102.15 (GND), U102.23 (GND1), U102.33 ((#HWB)PE2), U102.35 (GND2), U102.43 (GND3), U102.P$1 (PAD), Y1.2 (GND), Y1.4 (GND); also elsewhere on the board
MEGA_D14: U101.30 ((PCINT6/OC1B/OC4B/ADC13)PB6), U102.30 ((PCINT6/OC1B/OC4B/ADC13)PB6); also elsewhere on the board
MEGA_D15: U101.31 ((OC3A/#0C4A)PC6), U102.31 ((OC3A/#0C4A)PC6); also elsewhere on the board
MEGA_D16: U101.32 ((ICP3/CLK0/OC4A)PC7), U102.32 ((ICP3/CLK0/OC4A)PC7); also elsewhere on the board
MEGA_D28/A5: U101.36 ((ADC7/TDI)PF7), U102.36 ((ADC7/TDI)PF7); also elsewhere on the board
MEGA_D30/A4: U101.37 ((ADC6/TDO)PF6), U102.37 ((ADC6/TDO)PF6); also elsewhere on the board
MEGA_D32/A3: U101.38 ((ADC5/TMS)PF5), U102.38 ((ADC5/TMS)PF5); also elsewhere on the board
MEGA_D34/A2: U101.39 ((ADC4/TCK)PF4), U102.39 ((ADC4/TCK)PF4); also elsewhere on the board
unnamed: U101.22 ((XCK1/#CTS)PD5), U102.22 ((XCK1/#CTS)PD5)
unnamed: LED.A, R7.1
NC: U101.1 ((INT6/AIN0)PE6), U102.1 ((INT6/AIN0)PE6)
UCAP: C103.1, U101.6 (UCAP), U102.6 (UCAP)
USBID: AVRUSB.P4 (ID)
XTAL1: C107.1, R109.1, U101.17 (XTAL1), U102.17 (XTAL1), Y1.1 (C1)
XTAL2: C106.2, R109.2, U101.16 (XTAL2), U102.16 (XTAL2), Y1.3 (C2)

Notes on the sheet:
USB
Arduino Section
This section is derived from the Arduino Leonardo Design and has the same license.

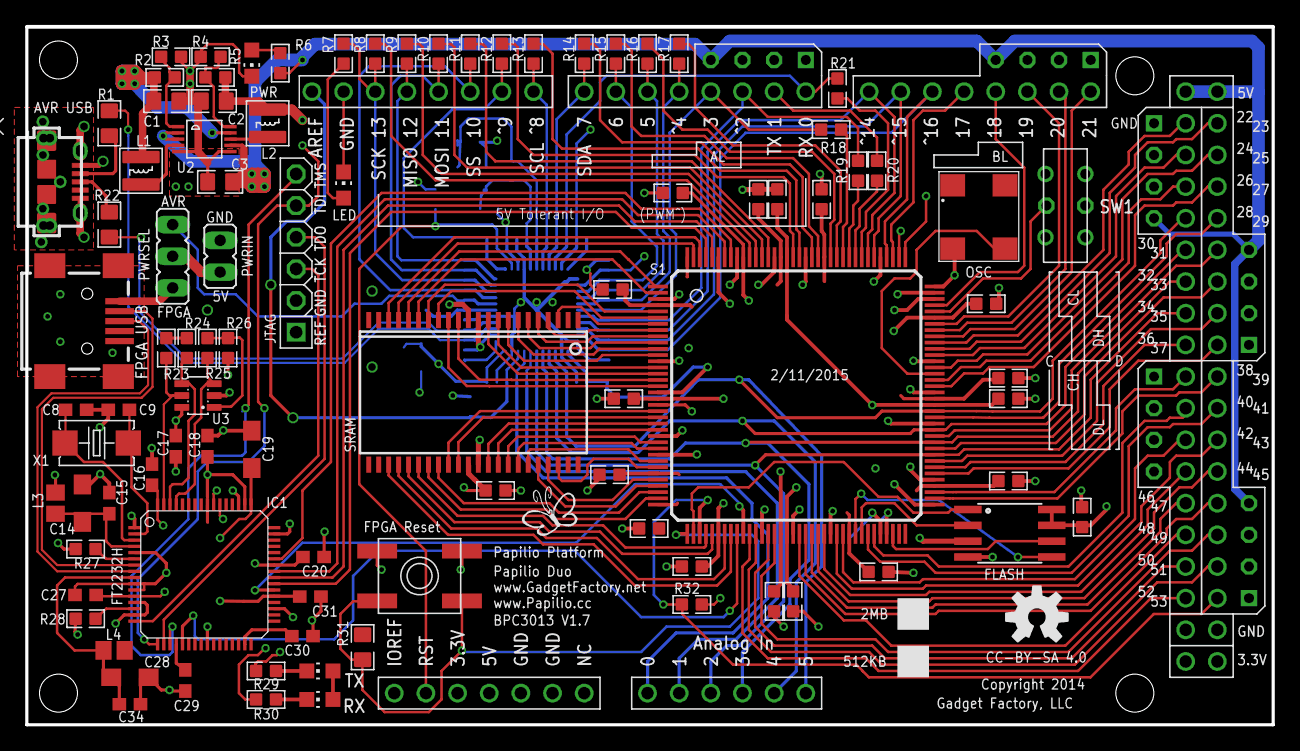
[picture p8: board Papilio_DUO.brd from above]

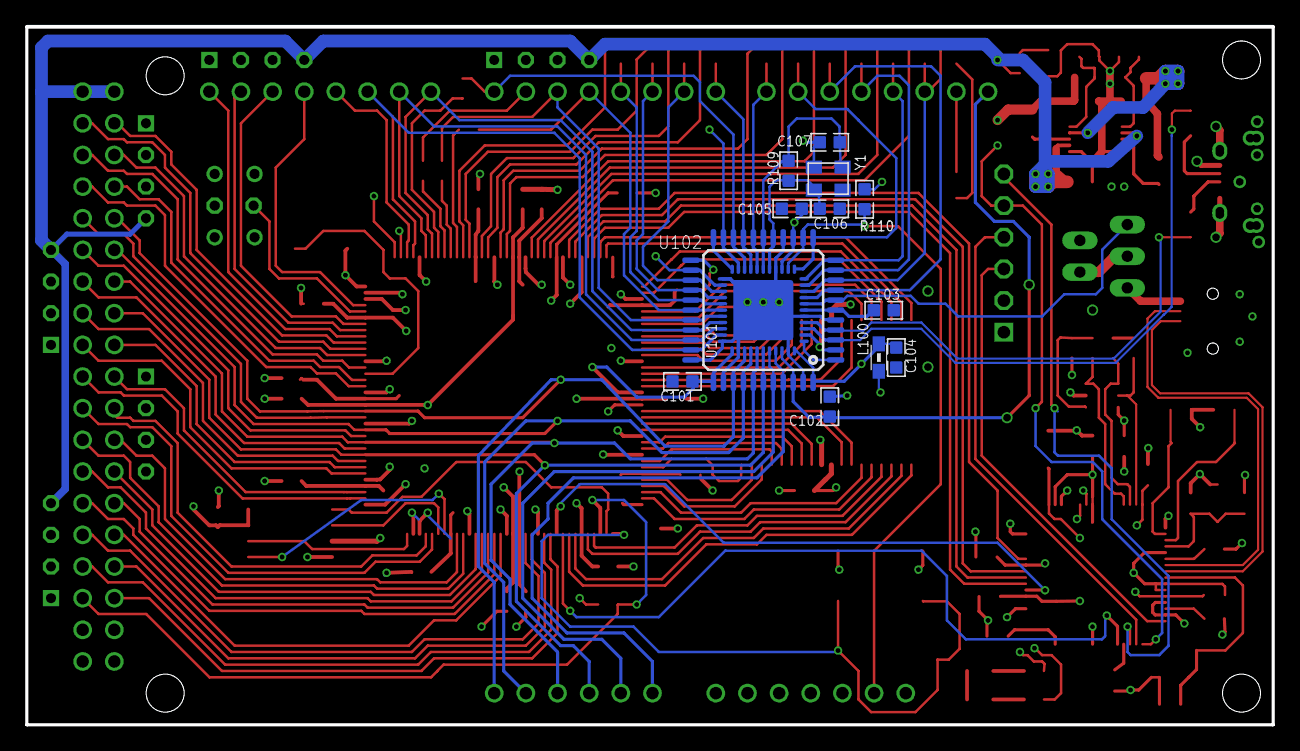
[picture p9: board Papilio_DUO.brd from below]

Board: 4 copper layers, 100.0 x 56.0 mm, 117 parts (13 on the bottom side), 160 nets.

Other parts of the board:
U$2, U$3, U$4, U$5: STAND-OFF-TIGHT
U$7: GADGETFACTORY_LOGO
U$9: OSHW-LOGO-M

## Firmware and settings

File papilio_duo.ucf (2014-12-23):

# UCF file for the Papilio DUO board
# Generated by pin_converter, written by Kevin Lindsey
# https://github.com/thelonious/papilio_pins/tree/development/pin_converter

# Main board wing pin [] to FPGA pin Pxx map
# -------C-------    -------B-------    -------A-------
# [GND] [C00] P114   [GND] [B00] P99    P100 [A15]
# [2V5] [C01] P115   [2V5] [B01] P97    P98 [A14]
# [3V3] [C02] P116   [3V3] [B02] P92    P93 [A13]
# [5V0] [C03] P117   [5V0] [B03] P87    P88 [A12]
#       [C04] P118         [B04] P84    P85 [A11] [5V0]
#       [C05] P119         [B05] P82    P83 [A10] [3V3]
#       [C06] P120         [B06] P80    P81 [A09] [2V5]
#       [C07] P121         [B07] P78    P79 [A08] [GND]
# [GND] [C08] P123   [GND] [B08] P74    P75 [A07]
# [2V5] [C09] P124   [2V5] [B09] P95    P67 [A06]
# [3V3] [C10] P126   [3V3] [B10] P62    P66 [A05]
# [5V0] [C11] P127   [5V0] [B11] P59    P61 [A04]
#       [C12] P131         [B12] P57    P58 [A03] [5V0]
#       [C13] P132         [B13] P55    P56 [A02] [3V3]
#       [C14] P133         [B14] P50    P51 [A01] [2V5]
#       [C15] P134         [B15] P47    P48 [A00] [GND]

## Prohibit the automatic placement of pins that are connected to VCC or GND for configuration.
CONFIG PROHIBIT=P144;
CONFIG PROHIBIT=P69;
CONFIG PROHIBIT=P60;

#NET "*" IOSTANDARD = LVTTL;

NET CLK      LOC="P94"  | IOSTANDARD=LVTTL;               										# CLK
TIMESPEC TS_Period_1 = PERIOD "CLK" 31.25 ns HIGH 50%;
NET TXD       LOC="P141" | IOSTANDARD=LVTTL | DRIVE=8 | SLEW=FAST;          										# TX
NET RXD       LOC="P46" | IOSTANDARD=LVTTL | DRIVE=8 | SLEW=FAST; 	    											# RX

NET Arduino_0          LOC="P116" | IOSTANDARD=LVTTL;                                # A0
NET Arduino_1          LOC="P117" | IOSTANDARD=LVTTL;                                # A1
NET Arduino_2          LOC="P118" | IOSTANDARD=LVTTL;                                # A2
NET Arduino_3          LOC="P119" | IOSTANDARD=LVTTL;                                # A3
NET Arduino_4          LOC="P120" | IOSTANDARD=LVTTL;                                # A4
NET Arduino_5          LOC="P121" | IOSTANDARD=LVTTL;                                # A5
NET Arduino_6          LOC="P123" | IOSTANDARD=LVTTL;                                # A6
NET Arduino_7          LOC="P124" | IOSTANDARD=LVTTL;                                # A7
NET Arduino_8          LOC="P126" | IOSTANDARD=LVTTL;                                # A8
NET Arduino_9          LOC="P127" | IOSTANDARD=LVTTL;                                # A9
NET Arduino_10         LOC="P131" | IOSTANDARD=LVTTL;                                # A10
NET Arduino_11         LOC="P132" | IOSTANDARD=LVTTL;                                # A11
NET Arduino_12         LOC="P133" | IOSTANDARD=LVTTL;                                # A12
NET Arduino_13         LOC="P134" | IOSTANDARD=LVTTL;                                # A13

NET Arduino_14          LOC="P115" | IOSTANDARD=LVTTL;                                # B0
NET Arduino_15          LOC="P114" | IOSTANDARD=LVTTL;                                # B1
NET Arduino_16          LOC="P112" | IOSTANDARD=LVTTL;                                # B2
NET Arduino_17          LOC="P111" | IOSTANDARD=LVTTL;                                # B3
NET Arduino_18          LOC="P105" | IOSTANDARD=LVTTL;                                # B4
NET Arduino_19          LOC="P102" | IOSTANDARD=LVTTL;                                # B5
NET Arduino_20          LOC="P101" | IOSTANDARD=LVTTL;                                # B6
NET Arduino_21          LOC="P100" | IOSTANDARD=LVTTL;                                # B7                        

NET Arduino_22          LOC="P99"  | IOSTANDARD=LVTTL;                                # C0
NET Arduino_24          LOC="P97"  | IOSTANDARD=LVTTL;                                # C1
NET Arduino_26          LOC="P93"  | IOSTANDARD=LVTTL;                                # C2
NET Arduino_28          LOC="P88"  | IOSTANDARD=LVTTL;                                # C3
NET Arduino_30          LOC="P85"  | IOSTANDARD=LVTTL;                                # C4
NET Arduino_32          LOC="P83"  | IOSTANDARD=LVTTL;                                # C5
NET Arduino_34          LOC="P81"  | IOSTANDARD=LVTTL;                                # C6
NET Arduino_36          LOC="P79"  | IOSTANDARD=LVTTL;                                # C7
NET Arduino_38          LOC="P75"  | IOSTANDARD=LVTTL;                                # C8
NET Arduino_40          LOC="P67"  | IOSTANDARD=LVTTL;                                # C9
NET Arduino_42         LOC="P62"  | IOSTANDARD=LVTTL;                                # C10
NET Arduino_44         LOC="P59"  | IOSTANDARD=LVTTL;                                # C11
NET Arduino_46         LOC="P57"  | IOSTANDARD=LVTTL;                                # C12
NET Arduino_48         LOC="P55"  | IOSTANDARD=LVTTL;                                # C13
NET Arduino_50         LOC="P50"  | IOSTANDARD=LVTTL;                                # C14
NET Arduino_52         LOC="P47"  | IOSTANDARD=LVTTL;                                # C15

NET Arduino_23     LOC="P98"  | IOSTANDARD=LVTTL ;                                
NET Arduino_25     LOC="P95" | IOSTANDARD=LVTTL ;                                	
NET Arduino_27     LOC="P92"  | IOSTANDARD=LVTTL ;                                
NET Arduino_29     LOC="P87"  | IOSTANDARD=LVTTL ;                                
NET Arduino_31     LOC="P84"  | IOSTANDARD=LVTTL ;                               
NET Arduino_33     LOC="P82"  | IOSTANDARD=LVTTL ;                              
NET Arduino_35     LOC="P80"  | IOSTANDARD=LVTTL ;                              
NET Arduino_37     LOC="P78"  | IOSTANDARD=LVTTL ;                            
NET Arduino_39     LOC="P74"  | IOSTANDARD=LVTTL ;                             
NET Arduino_41     LOC="P66"  | IOSTANDARD=LVTTL ;                            
NET Arduino_43     LOC="P61"  | IOSTANDARD=LVTTL ;                             
NET Arduino_45     LOC="P58"  | IOSTANDARD=LVTTL ;                               
NET Arduino_47     LOC="P56"  | IOSTANDARD=LVTTL ;                              
NET Arduino_49     LOC="P51"  | IOSTANDARD=LVTTL ;                             
NET Arduino_51     LOC="P48"  | IOSTANDARD=LVTTL ;                           
NET Arduino_53     LOC="P39"  | IOSTANDARD=LVTTL ;    

# SRAM
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

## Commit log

2014-01-06 Papilio Logic design
    [Papilio_Benchy.brd, Papilio_Benchy.sch]
2014-01-06 Replace power supply - not routed
    [Papilio_Benchy.brd, Papilio_Benchy.sch]
2014-01-06 FT2232H upgrade
    [Papilio_Benchy.brd, Papilio_Benchy.sch]
2014-01-06 Arduino Leonardo
    [Papilio_Benchy.brd, Papilio_Benchy.sch]
2014-01-09 Connections added and blocks placed.
    [Papilio_Benchy.brd, Papilio_Benchy.sch]
2014-02-03 Changed Arduino Mega footprint
2014-02-03 Bunch of little changes
    [Papilio_Benchy.brd, Papilio_Benchy.sch]
2014-02-03 Added switch and HDMI
    [Papilio_Benchy.brd, Papilio_Benchy.sch]
2014-02-04 Schematic Cleanup - Ready for routing...
    [Papilio_Benchy.brd, Papilio_Benchy.sch]
2014-02-05 Sram initiallly routed.
    [Papilio_Benchy.brd, Papilio_Benchy.sch]
2014-02-07 4 layers and all power planes fixed
    [Papilio_Benchy.brd]
2014-02-10 Place and route FT2232H
    [Papilio_Benchy.brd, Papilio_Benchy.sch]
2014-02-11 Power Supply PAR'd
    [Papilio_Benchy.brd, Papilio_Benchy.sch]
2014-02-11 SRAM Cleaned up
    [Papilio_Benchy.brd, Papilio_Benchy.sch]
2014-02-12 Before connecting Avr JTAG
    [Papilio_Benchy.brd, Papilio_Benchy.sch]
2014-02-14 Fully routed except for HDMI and AVR JTAG
    [Papilio_Benchy.brd, Papilio_Benchy.sch]
2014-02-14 Fully placed and routed! Needs verification and cleanup.
    [Papilio_Benchy.brd, Papilio_Benchy.sch]
2014-02-14 Cleanup layers and project directory
    [Papilio_Benchy.brd]
2014-02-18 Bad angles on traces fixed and DRC errors revisited.
    [Papilio_Benchy.brd]
2014-02-18 Silkscreen cleaned up.
    [Papilio_Benchy.brd, Papilio_Benchy.sch]
2014-02-18 Increased size of power and ground traces on USB connectors.
    [Papilio_Benchy.brd, Papilio_Benchy.sch]
2014-02-18 Fix missing pin 43 on AVR.
    [Papilio_Benchy.brd, Papilio_Benchy.sch]
2014-02-19 SPI pins moved to same location as the Uno
    [Papilio_Benchy.brd, Papilio_Benchy.sch]
2014-02-19 Added more info to silkscreen
    [Papilio_Benchy.brd, Papilio_Benchy.sch]
2014-02-20 Change HSWAP so I/O floats during config. Cleanup schematic sheets.
    [Papilio_Benchy.brd, Papilio_Benchy.sch]
2014-02-21 Cleanup silkscreen
    [Papilio_Benchy.brd, Papilio_Benchy.sch]
2014-02-24 Final fixes as pointed out in the forum.
    [Papilio_Benchy.brd, Papilio_Benchy.sch]
2014-03-04 Papilio DUO V1.0
    Submitted for PCB
    [Papilio_DUO.brd, Papilio_DUO.sch]
2014-03-05 Papilio DUO V1.1
    [Papilio_DUO.brd, Papilio_DUO.sch]
2014-03-18 Papilio DUO V1.2
    Changed size to 100CM for cheaper manufacturing
    [Papilio_DUO.brd, Papilio_DUO.sch]
2014-04-15 Routing changes: VBUS connected, RX/TX LED's connected to port B instead of A.
    [Papilio_DUO.brd, Papilio_DUO.sch]
2014-04-15 Silkscreen fixes, Reset re-worked so RST pin resets atmega32u4 instead of FPGA.
    [Papilio_DUO.brd, Papilio_DUO.sch]
2014-04-15 Remove HDMI
    [Papilio_DUO.brd, Papilio_DUO.sch]
2014-04-15 Default View
    [Papilio_DUO.brd]
2014-04-15 Cleaned up some HDMI traces.
    [Papilio_DUO.brd]
2014-04-16 Added Headers to the BOM
    [Papilio_DUO.brd, Papilio_DUO.sch]
2014-06-04 Papilio DUO V1.4
    Fixed the mounting holes.
    [Papilio_DUO.brd, Papilio_DUO.sch]
2014-07-30 minor changes to silkscreen.
    [Papilio_DUO.brd]
2014-09-30 Added TQFP footprint
    [Papilio_DUO.brd, Papilio_DUO.sch]
2014-09-30 Version 1.5 - Kickstarter Edition
    -Added TQFP footprint for the ATmega32U4
    -Changed values for LED resistors so they won't be so bright. R7, R29,
    R30
    -Changed size of the EEPROM used by the FT2232H chip from 1K to 2K. This
    allows us to look like official Xilinx Cable. U3
    -Fixed up some silkscreen markings to make it more obvious how to place
    the parts.
    -Added the Kickstarter Special Edition Marking
    -Changed PCB color to Black
    [Papilio_DUO.brd, Papilio_DUO.sch]
2014-12-23 Adding ucf and pdf schematic
2015-01-07 Version 1.6
    [Papilio_DUO.brd, Papilio_DUO.sch]
2015-02-11 Version 1.7
    Added 2MB and 512KB to top silkscreen
    [Papilio_DUO.brd]

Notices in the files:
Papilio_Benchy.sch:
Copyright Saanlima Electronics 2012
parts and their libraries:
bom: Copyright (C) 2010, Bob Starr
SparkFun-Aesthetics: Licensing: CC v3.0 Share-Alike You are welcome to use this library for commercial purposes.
